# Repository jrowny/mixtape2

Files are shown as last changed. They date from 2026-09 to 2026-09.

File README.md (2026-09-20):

# A PCB for my mixtape project

_NOTE:_ this revision has NOT been tested! I changed some things from the video including moving the encoderes to different GPIOs and fixing the microsd card. Please verify closely before ordering.

3D models here: https://makerworld.com/en/models/3335806-cassette-mixtape-mp3-player-2-0#profileId-3789001
Video here: https://youtu.be/otXrFBq0HWQ

## This project was sponsored by NextPCB

Get your first PCB order for $0.1 via NextPCB: https://www.nextpcb.com/?code=JonathanRowny
Build PCBA in days with fully automated assembly: https://www.nextpcb.com/rev0-pcb

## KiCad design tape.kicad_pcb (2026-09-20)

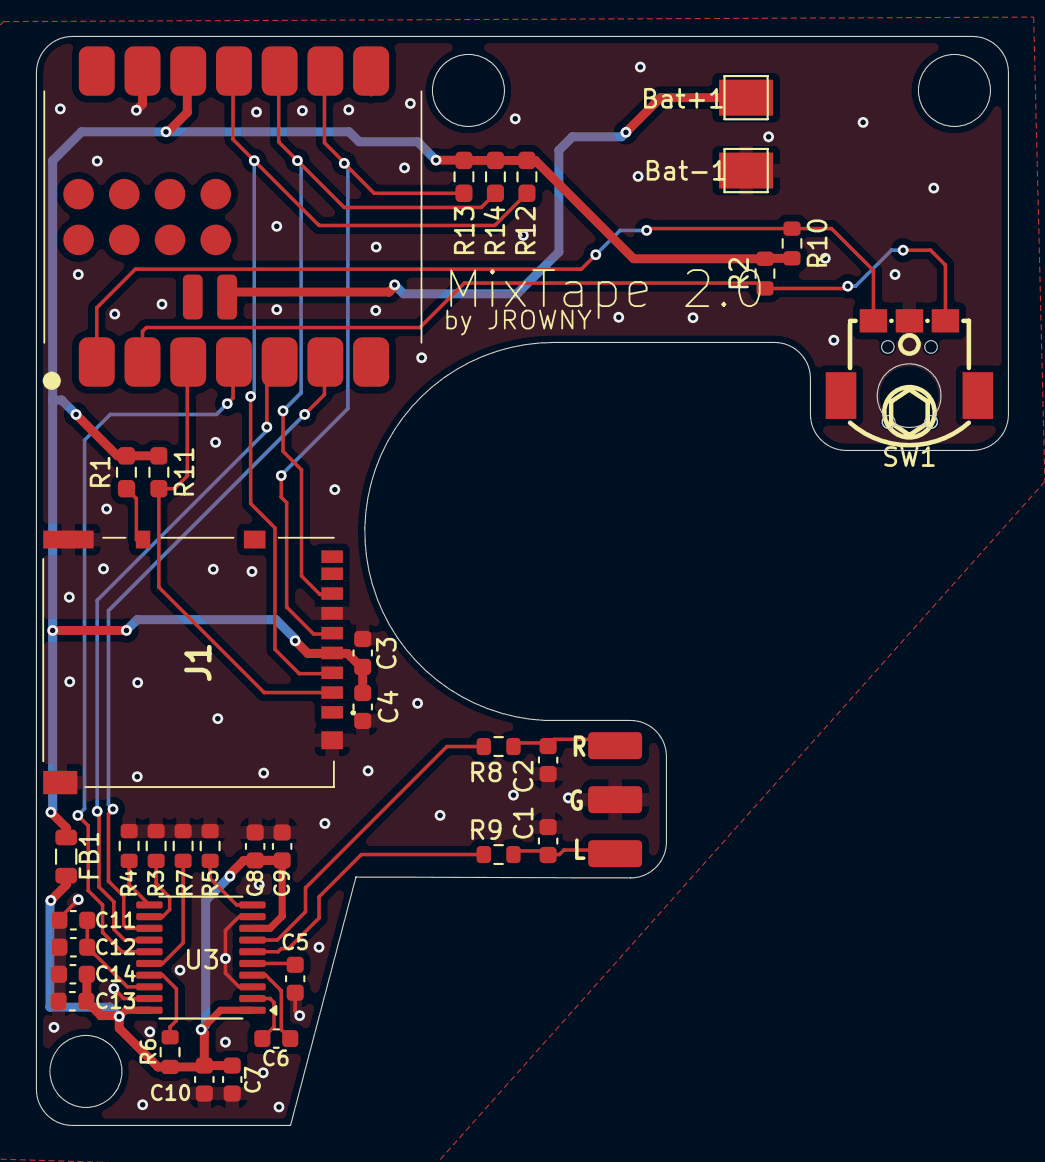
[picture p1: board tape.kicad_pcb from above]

Board: 2 copper layers, 54.0 x 60.5 mm, 36 parts (0 on the bottom side), 26 nets.

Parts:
Bat+1: Bat+; TestPoint_Pad_2.0x2.0mm
Bat-1: Bat-; TestPoint_Pad_2.0x2.0mm
C1, C2: 2.2nF; C_0603_1608Metric
C3, C7, C9, C11, C14: 10uf; C_0603_1608Metric
C4, C8, C10, C12, C13: 0.1uF; C_0603_1608Metric
C5, C6: 2.2uF; C_0603_1608Metric
FB1: FerriteBead_Small; L_0805_2012Metric
J1: Micro_SD_Card_Det_Hirose_DM3AT; DM3ATSFPEJM5
R1, R11, R12, R13, R14: 10k; R_0603_1608Metric_Pad0.98x0.95mm_HandSolder
R2, R3, R4, R5, R6, R7, R10: 10k; R_0603_1608Metric
R8, R9: 470; R_0603_1608Metric
SW1: RotaryEncoder; EC05E1220401-JRmoded
U1: XIAO-ESP32-S3-SMD; XIAO-ESP32S3-SMD
U2: audio_out
U3: PCM5102A; TSSOP-20_4.4x6.5mm_P0.65mm

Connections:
/3v3: C3.2, C4.2, FB1.1, J1.4 (VDD), R1.1, R2.2, R10.2, R11.1, R12.1, R13.1, R14.1, U1.12 (3V3)
/3v3f: C7.1, C8.1, C9.1, C10.1, C13.1, C14.2, FB1.2, R6.2, U3.1 (CPVDD), U3.8 (AVDD), U3.20 (DVDD)
/BAT: Bat+1.1 (1_1), U1.15 (BAT)
/ENC_A: R2.1, SW1.A, U1.2 (GPIO2_A1_D1)
/ENC_B: R10.1, SW1.B, U1.1 (GPIO1_A0_D0)
/I2S_BCLK: U1.6 (GPIO6_A5_D5_SCL), U3.13 (BCK)
/I2S_DATA: U1.5 (GPIO5_A4_D4_SDA), U3.14 (DIN)
/I2S_LRC: U1.4 (GPIO4_A3_D3), U3.15 (LRCK)
/LDOO: C11.2, C12.1, U3.18 (LDOO)
/OUT_L: C1.2, R9.1, U2.1 (audio_left)
/OUT_R: C2.1, R8.1, U2.3 (audio_right)
/SD_CS: J1.2 (DAT3/CD), R11.2, U1.3 (GPIO3_A2_D2)
/SPI_MISO: J1.7 (DAT0), R14.2, U1.10 (GPIO8_A9_D9_MISO)
/SPI_MOSI: J1.3 (CMD), R12.2, U1.11 (GPIO9_A10_D10_MOSI)
/SPI_SCK: J1.5 (CLK), R13.2, U1.9 (GPIO7_A8_D8_SCK)
GND: Bat-1.1 (1_1), C1.1, C2.2, C3.1, C4.1, C5.2, C7.2, C8.2, C9.2, C10.2, C11.1, C12.2, C13.2, C14.1, J1.6 (VSS), R3.1, R4.1, R5.1, R7.1, SW1.C, U1.13 (GND), U1.16 (GND), U2.2 (gnd), U3.3 (CPGND), U3.9 (AGND), U3.19 (DGND)
unnamed: C6.2, U3.4 (CAPM)
unnamed: C6.1, U3.2 (CAPP)
unnamed: R5.2, U3.10 (DEMP)
unnamed: R4.2, U3.11 (FLT)
unnamed: R7.2, U3.16 (FMT)
unnamed: R9.2, U3.6 (OUTL)
unnamed: R8.2, U3.7 (OUTR)
unnamed: R3.2, U3.12 (SCK)
unnamed: C5.1, U3.5 (VNEG)
unnamed: R6.1, U3.17 (XSMT)
